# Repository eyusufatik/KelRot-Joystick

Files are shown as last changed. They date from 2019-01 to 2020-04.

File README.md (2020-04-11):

# KelRot-Joystick
This repo includes all the files used to create a joystick for KelRot 5655's 2. driver for Destination: Deep Space. It provides easier operation with buttons placed considering the robot's subsystems' workflow.

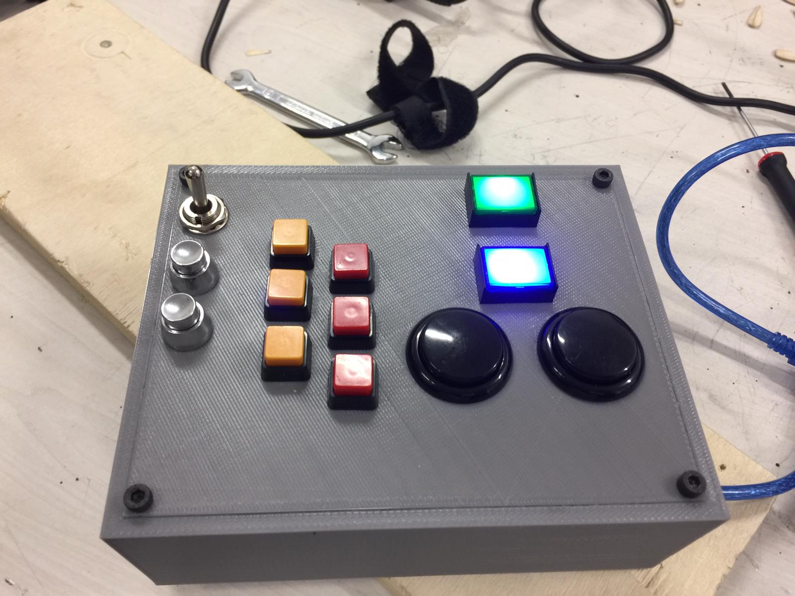
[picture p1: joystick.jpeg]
Assembled Joystick


## Buttons
1.  3 way switch in the top left corner
    -   At the start of a match, the co-pilot uses this switch to take out the intake mechanism.

2.  2 buttons under the switch
    -   These buttons provide manual operation of the lift system.

3.  6 buttons in the middle
    -   Each button sets the lift's height to the desired level of rocket. (e.g. orange buttton at the top sets the lift's height to the highest carho level of the rocket meanwhile red at the bottom sets it to the lowest hatch level of the rocket)
    
4.  2 lit up buttons on the right
    -   When pressed, upper one pushes the pnuematic tube forward in order to push the hatch out of the intake and the lower one pulls the tube back
    
5.  2 black buttons side by side
    -   These buttons are used for the cargo intake. When left one is pressed, intake mechanism takes the cargo in, when the right one is pressed the robot throws it.

## Arduino
An Arduino Uno is chosen as it has enough pins for the buttons on the joystick and can be found laying around in KelRot's workplace. With UnoJoy library's special firmware, Arduino Uno shows up as a joystick on most of the operating systems (Windows, Linux, MacOS). Information on UnoJoy library can be found here: https://code.google.com/archive/p/unojoy/.

## Cad
Mechanical parts are designed on Autodesk Fusion 360 and 3D printed with PLA. Simply use 4 M4 screws to assemble.
Button holes are .5 mm wider than the buttons to make assembly easier.

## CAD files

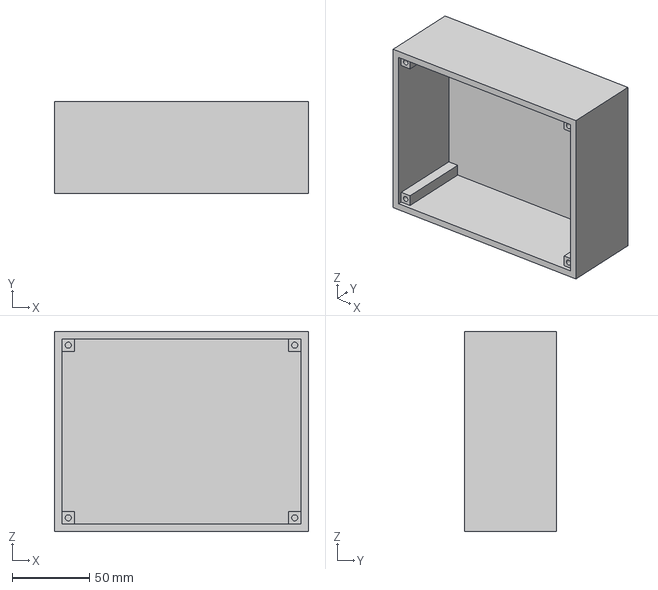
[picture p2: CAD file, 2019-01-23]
CAD/Box.step
164.9 x 60.0 x 130.0 mm

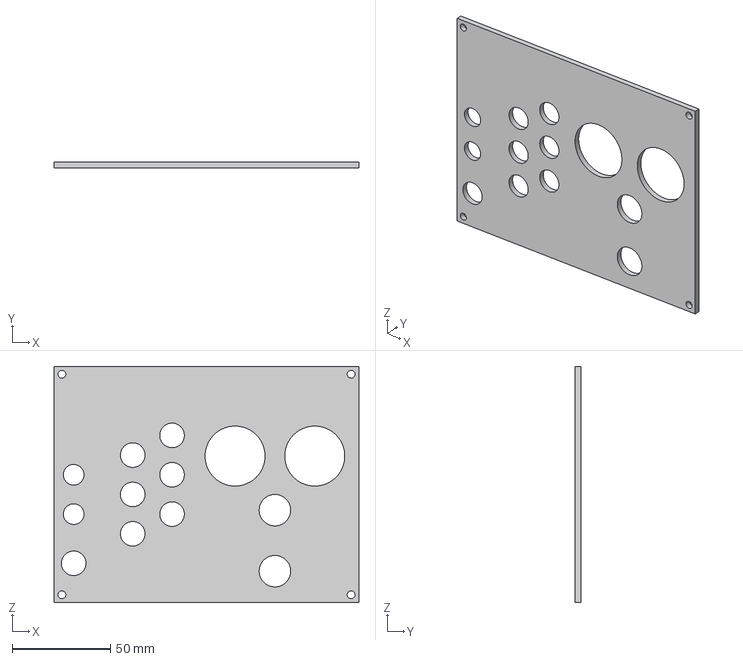
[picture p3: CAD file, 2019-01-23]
CAD/Cover.step
155.0 x 3.00 x 120.1 mm

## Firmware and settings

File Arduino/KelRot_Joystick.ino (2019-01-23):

#include "UnoJoy.h"

void setup() {
  Serial.begin(9600);
  setupUnoJoy();
  
  //set pins with pull up mode so less cabling and components are required
  for(int i=2;i<=13;i++){
    pinMode(i,INPUT_PULLUP);
  }
  pinMode(18,INPUT_PULLUP);
  pinMode(19,INPUT_PULLUP);
}

void loop() {
  //create a blank controller data
  dataForController_t controllerData = getBlankDataForController();

  //set joystick buttons
  //see schematics for which pin is for which button
  controllerData.squareOn = !digitalRead(2);
  controllerData.crossOn = !digitalRead(3);
  controllerData.circleOn = !digitalRead(4);
  controllerData.triangleOn = !digitalRead(5);
  
  controllerData.l1On = !digitalRead(6);
  controllerData.r1On = !digitalRead(7);
  
  controllerData.l2On = !digitalRead(8);
  controllerData.r2On = !digitalRead(9);
  
  controllerData.l3On = !digitalRead(12);
  controllerData.r3On = !digitalRead(13);
  
  controllerData.selectOn = !digitalRead(10);
  controllerData.startOn = !digitalRead(11);

  //UnoJoy library doesn't provide enough buttons so use pov instead
  controllerData.dpadDownOn = !digitalRead(18); //A4
  controllerData.dpadUpOn = !digitalRead(19); //A5

  //send data
  setControllerData(controllerData);
}

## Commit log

2019-01-23 Initial commit, I guess.
    [Box.step, Cover.step]
2019-01-23 Added arduino files
